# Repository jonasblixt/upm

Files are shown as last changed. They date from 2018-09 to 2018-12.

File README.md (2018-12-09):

## UPM - USB Power Monitor

This device monitors current and voltage for USB powered devices.

# Hardware
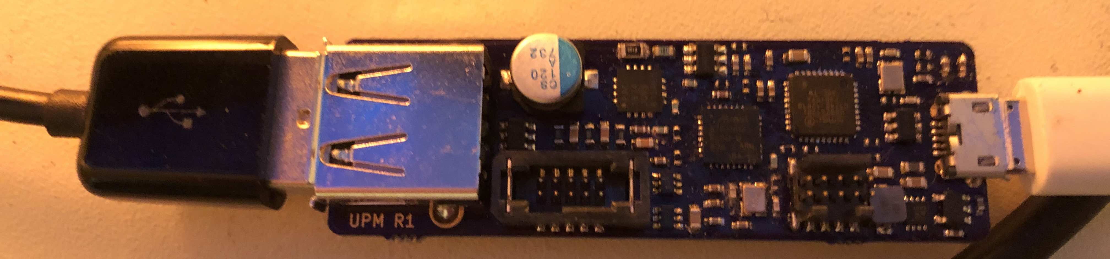
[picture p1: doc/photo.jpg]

Assembled PCB 

The PCB is a four layer board, manufactured by OSH Park. The boards can
 be ordered [here](https://oshpark.com/shared_projects/uE5lZDkP)

Schematics, layout and BOM can be found [here](https://github.com/jonpe960/upm/tree/master/hw/Release/R1)

# System description
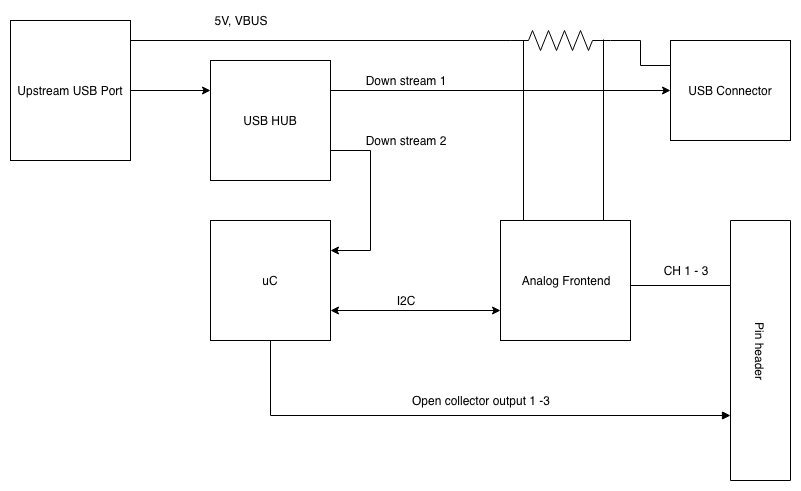
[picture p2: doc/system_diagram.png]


The device has a built in, two port, USB hub. One of the down stream ports
connects to the USB A connector and the other down stream port is connected to
the microcontroller.

An integrade analog frontend that contains a 16 bit ADC and differential
amplifier measures the voltage and current of the down stream VBUS supply. Three
auxillary diff inputs are available on a pin header.

It is possible to control the output VBUS with the on board power switch, which
also has built in short circuit protection. Three auxillary, open collector,
outputs are available on pin header.

# Ncurses TUI

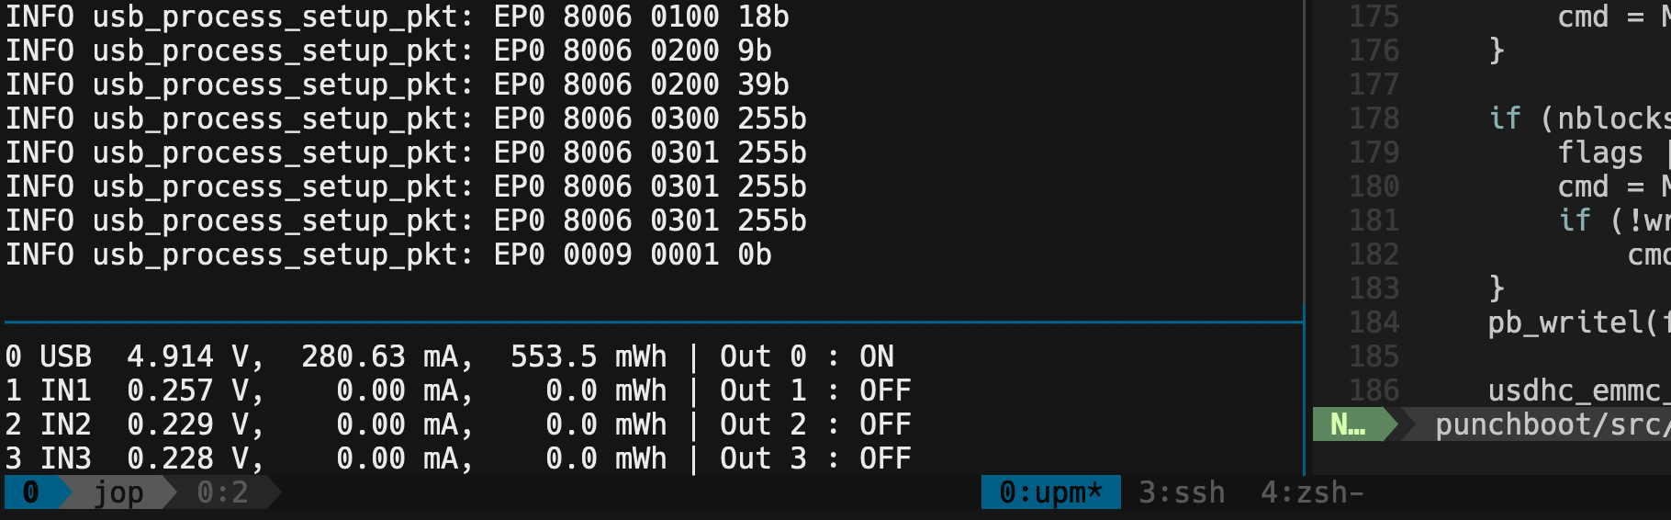
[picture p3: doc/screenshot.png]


The ncurses based TUI, displaying voltage, current and energy usage. 
Outputs can be controled from the TUI:
 - A/a VBUS on/off
 - S/s out1 on/off
 - D/d out2 on/off
 - F/f out3 on/off
 - r Reset energy counters

# Intended usage

This project came from a need to remotley monitor and power cycle USB powered devices.

# Future improvements

 - Add domain/tcp socket listener for remote control
 - Support for logging

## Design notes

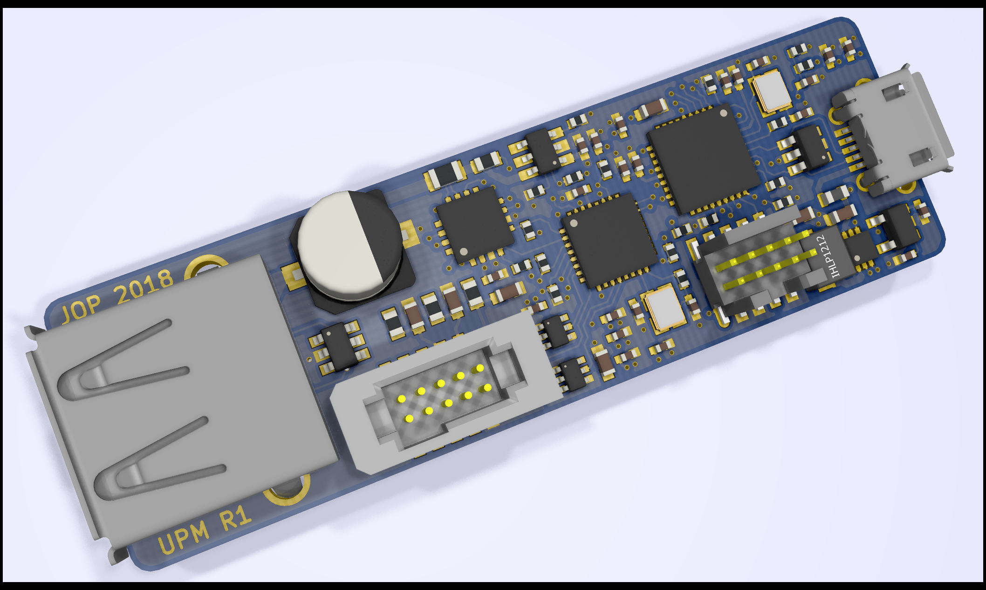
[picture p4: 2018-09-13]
hw/Release/R1/UPM R1 render.png

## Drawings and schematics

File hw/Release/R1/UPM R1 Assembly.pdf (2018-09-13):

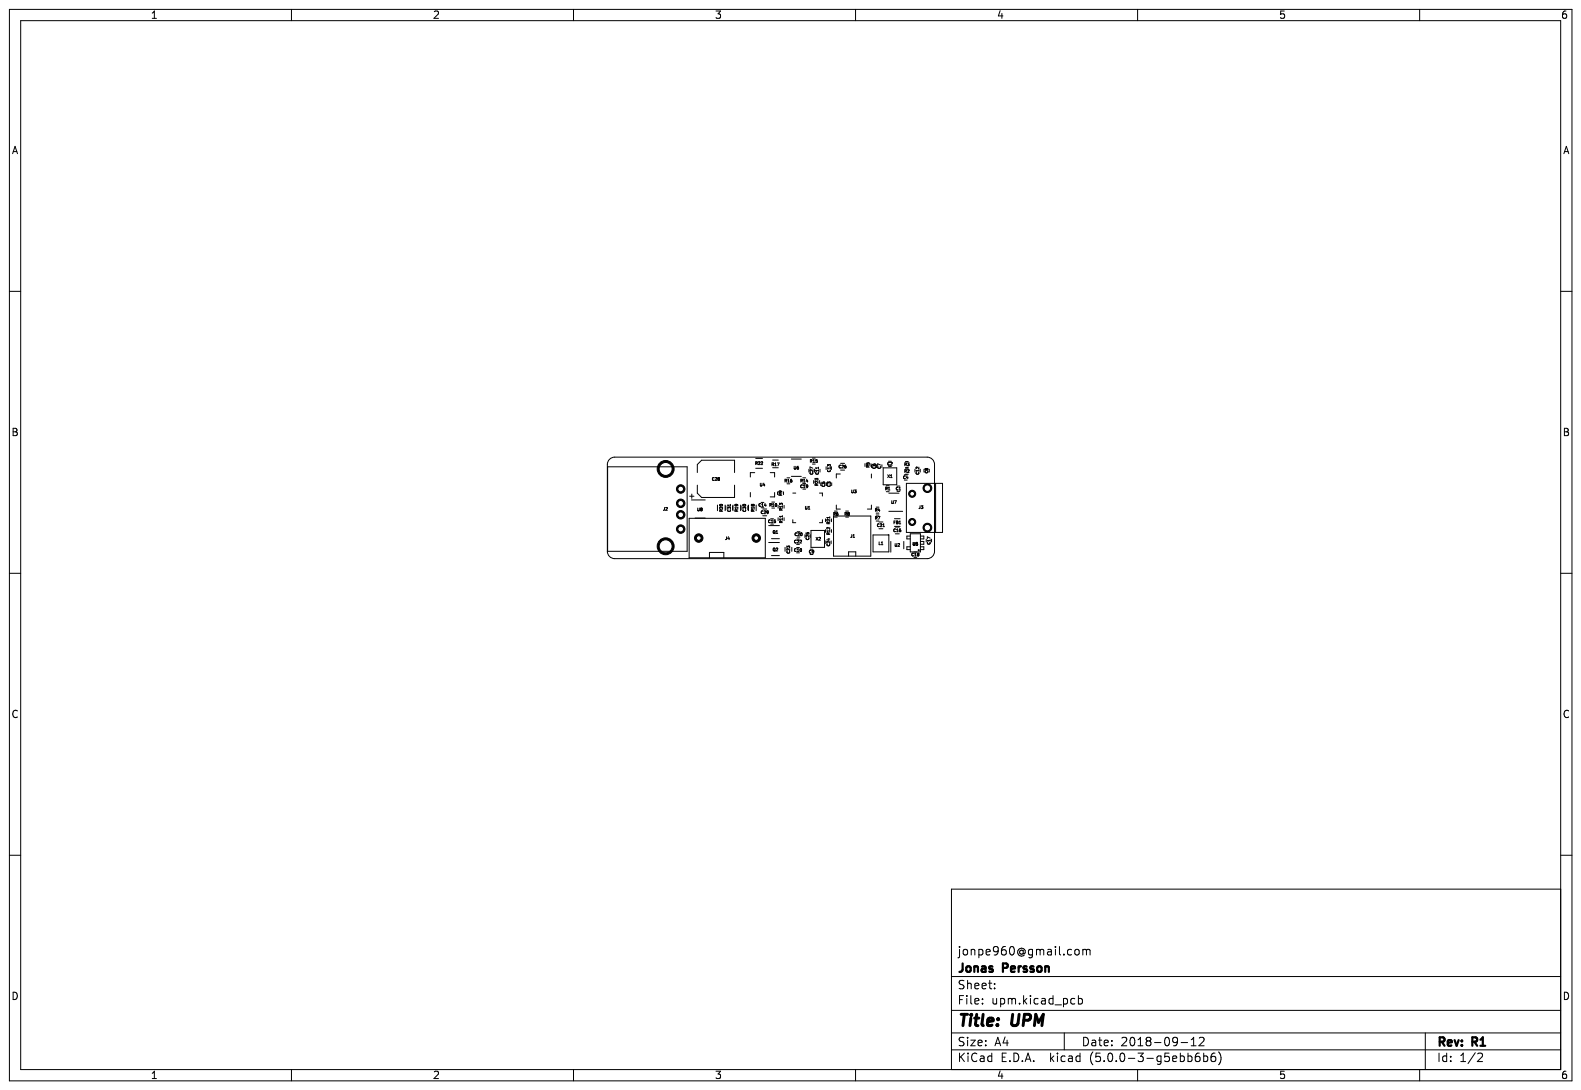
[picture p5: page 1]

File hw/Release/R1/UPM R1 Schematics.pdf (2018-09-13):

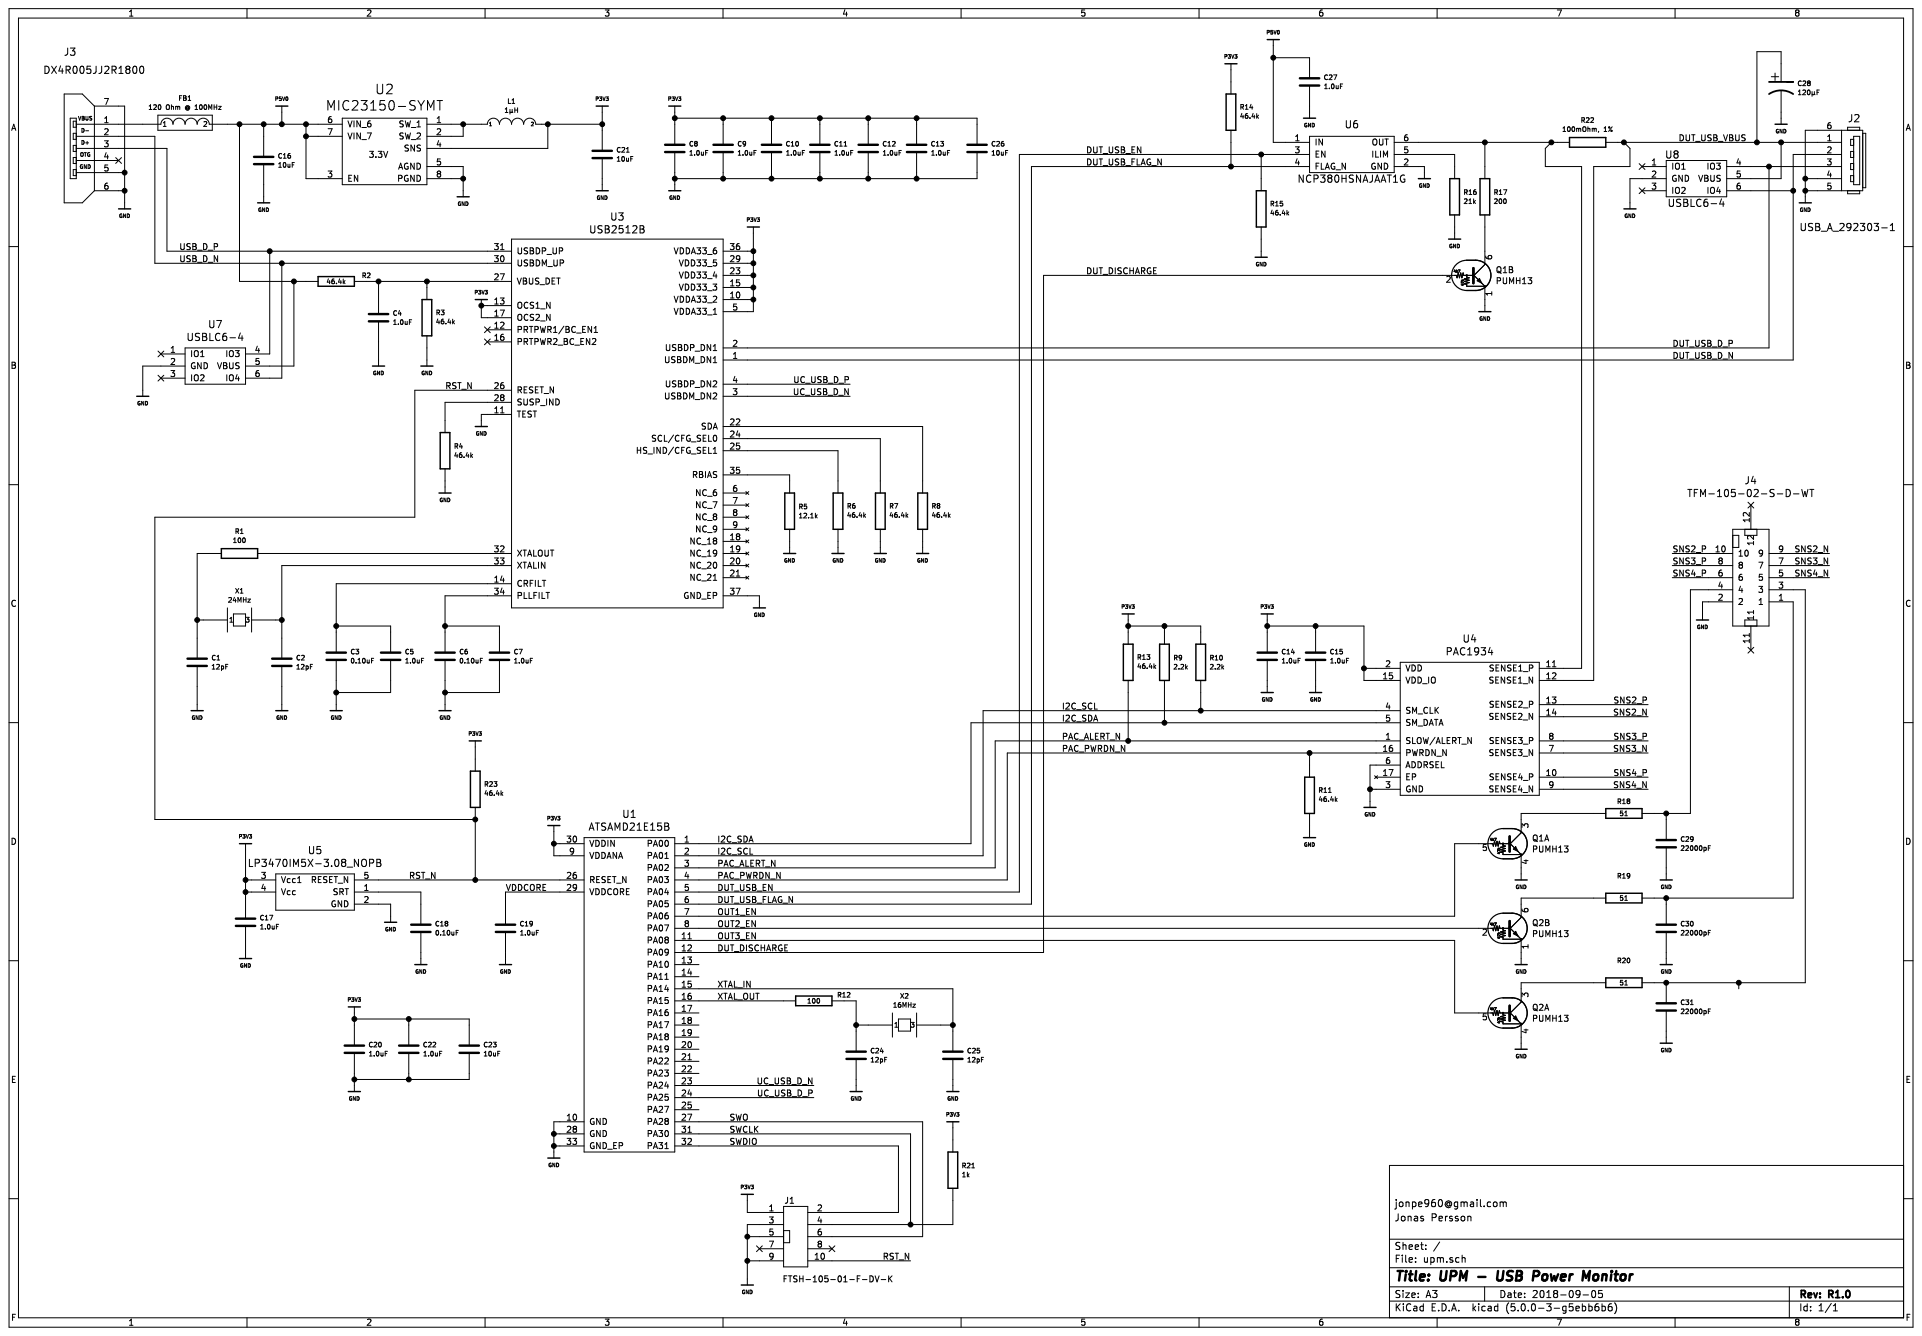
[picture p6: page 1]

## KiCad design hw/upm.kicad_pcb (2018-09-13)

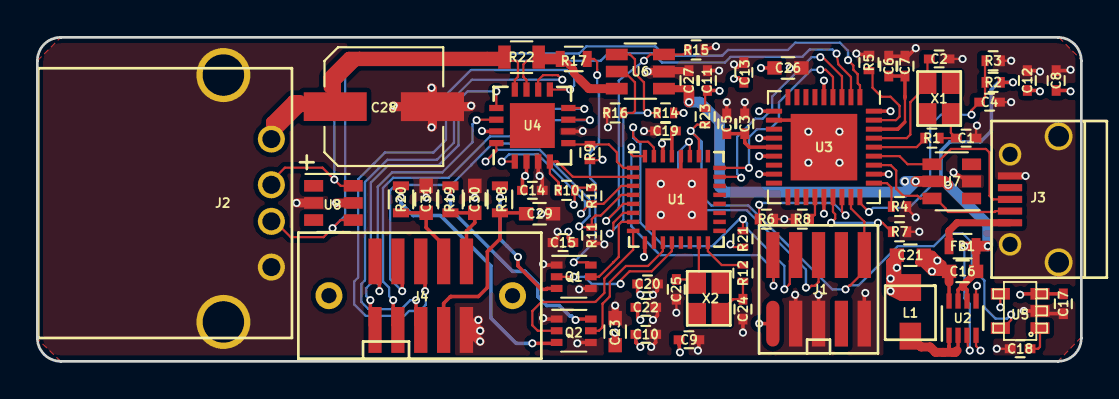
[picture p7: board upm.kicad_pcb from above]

Board: 4 copper layers, 58.0 x 18.0 mm, 72 parts (0 on the bottom side), 57 nets.

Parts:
C1, C2, C24, C25: C0402_12p_25Vdc_C0G_2; C0402
C3, C6, C18: C0402_100n_25Vdc_X7R; C0402
C4, C5, C7, C8, C9, C10, C11, C12, C13, C14, C15, C17, C19, C20, C22, C27: C0402_1u_6.3Vdc_X7R; C0402
C16, C21, C23, C26: C0603_10u_10Vdc_X7R; C0603
C28: PCAP_120u_4; CP_Elec_6.3x5.8
C29, C30, C31: C0603_22n_100Vdc_X7R; C0603
FB1: BL0603_BLM18BB121SN1D; L0603
J1: FTSH-105-01-F-DV-K
J2: USB_A_292303-1; USB_A_TH
J3: DX4R005JJ2R1800; USB_Micro-B
J4: TFM-105-02-S-D-WT
L1: IHLP1212_1u_1; IHLP1212
Q1, Q2: PUMH13; SOT-363_SC-70-6
R1, R12: R0402_100R; R0402
R2, R3, R4, R6, R7, R8, R11, R13, R14, R15, R23: R0402_46k40; R0402
R5: R0402_12k10; R0402
R9, R10: R0402_2k20; R0402
R16: R0402_21k; R0402
R17: R0603_200R; R0603
R18, R19, R20: R0603_51R; R0603
R21: R0402_1k; R0402
R22: R0805_0R1; R0805
U1: ATSAMD21E15B; QFN-32-1EP_5x5mm_Pitch0.5mm
U2: MIC23150-SYMT; DFN-8_2x2mm_Pitch0.5mm
U3: USB2512B; QFN-36-1EP_6x6mm_Pitch0.5mm
U4: PAC1934; QFN-16-1EP_4x4mm_Pitch0.65mm
U5: LP3470IM5X-3.08_NOPB; SOT-23-5
U6: NCP380HSNAJAAT1G; TSOT-23-6
U7, U8: USBLC6-4; SOT-23-6
X1: NX2520SA-24.000000MHZ; NX2520SA
X2: NX2520SA-16.000000MHZ; NX2520SA

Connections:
/DUT_DISCHARGE: Q1.2, U1.12
/DUT_USB_D_N: J2.2, U3.1, U8.6
/DUT_USB_D_P: J2.3, U3.2, U8.4
/DUT_USB_EN: R15.2, U1.5, U6.3
/DUT_USB_FLAG_N: R14.1, U1.6, U6.4
/DUT_USB_VBUS: C28.1, J2.1, R22.1, U4.12, U8.5
/I2C_SCL: R10.2, U1.2, U4.4
/I2C_SDA: R9.2, U1.1, U4.5
/OUT1_EN: Q1.5, U1.7
/OUT2_EN: Q2.2, U1.8
/OUT3_EN: Q2.5, U1.11
/PAC_ALERT_N: R13.1, U1.3, U4.1
/PAC_PWRDN_N: R11.2, U1.4, U4.16
/RST_N: J1.10, R23.1, U1.26, U3.26, U5.5
/SNS2_N: J4.9, U4.14
/SNS2_P: J4.10, U4.13
/SNS3_N: J4.7, U4.7
/SNS3_P: J4.8, U4.8
/SNS4_N: J4.5, U4.9
/SNS4_P: J4.6, U4.10
/SWCLK: J1.4, R21.2, U1.31
/SWDIO: J1.2, U1.32
/SWO: J1.6, U1.27
/UC_USB_D_N: U1.23, U3.3
/UC_USB_D_P: U1.24, U3.4
/USB_D_N: J3.2, U3.30, U7.6
/USB_D_P: J3.3, U3.31, U7.4
/VDDCORE: C19.1, U1.29
/XTAL_IN: C25.1, U1.15, X2.3
/XTAL_OUT: R12.2, U1.16
GND: C1.2, C2.2, C3.2, C4.2, C5.2, C6.2, C7.2, C8.2, C9.2, C10.2, C11.2, C12.2, C13.2, C14.2, C15.2, C16.2, C17.2, C18.2, C19.2, C20.2, C21.2, C22.2, C23.2, C24.2, C25.2, C26.2, C27.2, C28.2, C29.2, C30.2, C31.2, J1.3, J1.5, J1.9, J2.4, J2.5, J2.6, J3.5, J3.6, J3.7, J4.2, Q1.1, Q1.4, Q2.1, Q2.4, R3.1, R4.2, R5.2, R6.1, R7.1, R8.1, R11.1, R15.1, R16.2, U1.10, U1.28, U1.33, U2.5, U2.8, U3.11, U3.37, U4.3, U4.6, U5.2, U6.2, U7.2, U8.2
unnamed: C1.1, R1.2, X1.1
unnamed: C2.1, U3.33, X1.3
unnamed: C3.1, C5.1, U3.14
unnamed: C4.1, R2.1, R3.2, U3.27
unnamed: C6.1, C7.1, U3.34
unnamed: C18.1, U5.1
unnamed: C24.1, R12.1, X2.1
unnamed: C29.1, J4.4, R18.1
unnamed: C30.1, J4.1, R19.1
unnamed: C31.1, J4.3, R20.1
unnamed: FB1.1, J3.1
unnamed: L1.1, U2.1, U2.2
unnamed: Q1.3, R18.2
unnamed: Q1.6, R17.2
unnamed: Q2.3, R20.2
unnamed: Q2.6, R19.2
unnamed: R1.1, U3.32
unnamed: R4.1, U3.28
unnamed: R5.1, U3.35
unnamed: R6.2, U3.25
unnamed: R7.2, U3.24
unnamed: R8.2, U3.22
unnamed: R16.1, U6.5
unnamed: R17.1, R22.2, U4.11, U6.6
P3V3: C8.1, C9.1, C10.1, C11.1, C12.1, C13.1, C14.1, C15.1, C17.1, C20.1, C21.1, C22.1, C23.1, C26.1, J1.1, L1.2, R9.1, R10.1, R13.2, R14.2, R21.1, R23.2, U1.9, U1.30, U2.4, U3.5, U3.10, U3.13, U3.15, U3.17, U3.23, U3.29, U3.36, U4.2, U4.15, U5.3, U5.4
P5V0: C16.1, C27.1, FB1.2, R2.2, U2.3, U2.6, U2.7, U6.1, U7.5

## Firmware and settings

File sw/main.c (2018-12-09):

/**
 * UPM
 *
 * Copyright (C) 2018 Jonas Persson <jonpe960@gmail.com>
 *
 * SPDX-License-Identifier: BSD-3-Clause
 *
 */
#include <stdint.h>

#include "samd21.h"
#include "usb.h"
#include "upm.h"
#include "i2c.h"
#include "protocol.h"
#include "pac193x.h"

int main(void)
{
    uint32_t reg;

    /* Unused PIN Configuration */
    write32(PORT + PORT_DIRSET, UNUSED_PINS);
    write32(PORT + PORT_OUTCLR, UNUSED_PINS);

    /* Configure outputs */
    write32(PORT + PORT_DIRSET, PIN_DUT_USB_EN);
    write32(PORT + PORT_DIRSET, PIN_PACPWRDN_N);
    write32(PORT + PORT_DIRSET, PIN_OUT1_EN);
    write32(PORT + PORT_DIRSET, PIN_OUT2_EN);
    write32(PORT + PORT_DIRSET, PIN_OUT3_EN);
    write32(PORT + PORT_DIRSET, PIN_DUT_DISCHARGE);

    /* Configure inputs */
    write32(PORT + PORT_DIRCLR, PIN_PAC_ALERT_N);
    write32(PORT + PORT_DIRCLR, PIN_DUT_USB_FLAG_N);


    /* Set output default values */
    write32(PORT + PORT_OUTSET, PIN_DUT_USB_EN);
    write32(PORT + PORT_OUTSET, PIN_PACPWRDN_N);
    write32(PORT + PORT_OUTCLR, PIN_OUT1_EN);
    write32(PORT + PORT_OUTCLR, PIN_OUT2_EN);
    write32(PORT + PORT_OUTCLR, PIN_OUT3_EN);
    write32(PORT + PORT_OUTCLR, PIN_DUT_DISCHARGE);

    /* PAD Mux */
    
    /* PA1 = Sercom1/pad1, PA0 = Sercom1/pad0 */

    write32(PORT + PORT_WRCONFIG, (1 << 30) | (1 << 28) | 
                                  (MUX_D << 24) |
                                  (1 << 16) |
                                  (1 << 0) |
                                  (1 << 1));

    /* PA25 = USB_DP, PA24 = USB_DM */

    write32(PORT + PORT_WRCONFIG, (1 << 31) | (1 << 30) | (1 << 28) | 
                                  (MUX_G << 24) |
                                  (1 << 16) |
                                  (1 << 8) |
                                  (1 << 9));


    /* Enable SERCOM 1 clock */
    reg = read32(PM + PM_APBCMASK);
    reg |= (1 << 3);
    write32(PM + PM_APBCMASK, reg);
    
    write16(GCLK + GCLK_CLKCTRL, (1 << 14) | GCLK_ID_SERCOMx_SLOW);
    write16(GCLK + GCLK_CLKCTRL, (1 << 14) | GCLK_ID_SERCOM1_CORE);

    //write32(NVIC_ISER, (1 << SERCOM1_IRQn));

    i2c_init(SERCOM1);


    /* Enable and connect USB clock to generator 0 */
    write16(GCLK + GCLK_CLKCTRL, (1 << 14) | GCLK_ID_USB);

    pac193x_init(0x20);

    usb_init(USB);
    struct upm_in in;

    while(1) 
    {
        usb_task();

        if (usb_enumerated()) 
        {
            
            pac193x_refresh();

            for (uint32_t i = 0; i < 0xfff; i++)
                asm("nop");

            for (uint32_t i = 0; i < 4; i++)
            {
                in.Vbus[i] = pac193x_vbus(i);
                in.Vsns[i] = pac193x_vsns(i);
                pac193x_pwr(i, in.Ereg[i]);
            }

            usb_send((uint8_t *) &in, sizeof(struct upm_in));

            if (usb_has_data())
            {
                struct upm_out *out = (struct upm_out *) usb_get_buf();

                if (out->outputs_set & (1 << 0))
                {
                    in.outputs |= (1 << 0);
                    write32(PORT + PORT_OUTCLR, PIN_DUT_DISCHARGE);
                    write32(PORT + PORT_OUTSET, PIN_DUT_USB_EN);
                }

                if (out->outputs_clr & (1 << 0))
                {
                    in.outputs &= ~(1 << 0); 
                    write32(PORT + PORT_OUTSET, PIN_DUT_DISCHARGE);
                    write32(PORT + PORT_OUTCLR, PIN_DUT_USB_EN);
                }


                if (out->outputs_set & (1 << 1))
                {
                    in.outputs |= (1 << 1);
                    write32(PORT + PORT_OUTSET, PIN_OUT1_EN);
                }


                if (out->outputs_clr & (1 << 1))
                {
                    in.outputs &= ~(1 << 1);
                    write32(PORT + PORT_OUTCLR, PIN_OUT1_EN);
                }


                if (out->outputs_set & (1 << 2))
                {
                    in.outputs |= (1 << 2);
                    write32(PORT + PORT_OUTSET, PIN_OUT2_EN);
                }


                if (out->outputs_clr & (1 << 2))
                {
                    in.outputs &= ~(1 << 2);
                    write32(PORT + PORT_OUTCLR, PIN_OUT2_EN);
                }


                if (out->outputs_set & (1 << 3))
                {
                    in.outputs |= (1 << 3);
                    write32(PORT + PORT_OUTSET, PIN_OUT3_EN);
                }


                if (out->outputs_clr & (1 << 3))
                {
                    in.outputs &= ~(1 << 3);
                    write32(PORT + PORT_OUTCLR, PIN_OUT3_EN);
                }

                if (out->counter_reset & (1 << 0))
                {
                    pac193x_reset_counters();
                }

            }

        }
    }
}

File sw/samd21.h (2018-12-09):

/**
 * UPM
 *
 * Copyright (C) 2018 Jonas Persson <jonpe960@gmail.com>
 *
 * SPDX-License-Identifier: BSD-3-Clause
 *
 */
#ifndef __SAMD21_H__
#define __SAMD21_H__

#include <stdint.h>

static inline void write32(uint32_t reg, uint32_t val)
{
    *((volatile uint32_t *) reg) = val;
}

static inline uint32_t read32(uint32_t reg)
{
    return *((volatile uint32_t *)reg);
}


static inline void write16(uint32_t reg, uint16_t val)
{
    *((volatile uint16_t *) reg) = val;
}

static inline uint16_t read16(uint32_t reg)
{
    return *((volatile uint16_t *)reg);
}


static inline void write8(uint32_t reg, uint8_t val)
{
    *((volatile uint8_t *) reg) = val;
}

static inline uint8_t read8(uint32_t reg)
{
    return *((volatile uint8_t *)reg);
}

/* Cortex M0+ Registers */

#define SCS_BASE                       (0xE000E000)
#define SysTick_BASE        (SCS_BASE +  0x0010UL)                    /*!< SysTick Base Address */
#define NVIC_BASE           (SCS_BASE +  0x0100UL)                    /*!< NVIC Base Address */
#define SCB_BASE            (SCS_BASE +  0x0D00UL)                    /*!< System Control Block Base Address */

#define NVIC_ISER           (NVIC_BASE + 0x000)
#define NVIC_ICER           (NVIC_BASE + 0x080)
#define NVIC_ISPR           (NVIC_BASE + 0x100)
#define NVIC_ICPR           (NVIC_BASE + 0x180)
#define NVIC_IP             (NVIC_BASE + 0x300)

/* SAMD21 Registers */

#define AC                            (0x42004400) /**< \brief (AC) APB Base Address */
#define ADC                           (0x42004000) /**< \brief (ADC) APB Base Address */
#define DAC                           (0x42004800) /**< \brief (DAC) APB Base Address */
#define DMAC                          (0x41004800) /**< \brief (DMAC) APB Base Address */
#define DSU                           (0x41002000) /**< \brief (DSU) APB Base Address */
#define EIC                           (0x40001800) /**< \brief (EIC) APB Base Address */
#define EVSYS                         (0x42000400) /**< \brief (EVSYS) APB Base Address */
#define GCLK                          (0x40000C00) /**< \brief (GCLK) APB Base Address */
#define SBMATRIX                      (0x41007000) /**< \brief (SBMATRIX) APB Base Address */
#define I2S                           (0x42005000) /**< \brief (I2S) APB Base Address */
#define MTB                           (0x41006000) /**< \brief (MTB) APB Base Address */
#define NVMCTRL_AUX3                  (0x0080A000) /**< \brief (NVMCTRL) AUX3 Base Address */
#define NVMCTRL                       (0x41004000) /**< \brief (NVMCTRL) APB Base Address */
#define NVMCTRL_CAL                   (0x00800000) /**< \brief (NVMCTRL) CAL Base Address */
#define NVMCTRL_LOCKBIT               (0x00802000) /**< \brief (NVMCTRL) LOCKBIT Base Address */
#define NVMCTRL_OTP1                  (0x00806000) /**< \brief (NVMCTRL) OTP1 Base Address */
#define NVMCTRL_OTP2                  (0x00806008) /**< \brief (NVMCTRL) OTP2 Base Address */
#define NVMCTRL_OTP4                  (0x00806020) /**< \brief (NVMCTRL) OTP4 Base Address */
#define NVMCTRL_TEMP_LOG              (0x00806030) /**< \brief (NVMCTRL) TEMP_LOG Base Address */
#define NVMCTRL_USER                  (0x00804000) /**< \brief (NVMCTRL) USER Base Address */
#define PAC0                          (0x40000000) /**< \brief (PAC0) APB Base Address */
#define PAC1                          (0x41000000) /**< \brief (PAC1) APB Base Address */
#define PAC2                          (0x42000000) /**< \brief (PAC2) APB Base Address */
#define PM                            (0x40000400) /**< \brief (PM) APB Base Address */
#define PORT                          (0x41004400) /**< \brief (PORT) APB Base Address */
#define PORT_IOBUS                    (0x60000000) /**< \brief (PORT) IOBUS Base Address */
#define PTC                           (0x42004C00) /**< \brief (PTC) APB Base Address */
#define RTC                           (0x40001400) /**< \brief (RTC) APB Base Address */
#define SERCOM0                       (0x42000800) /**< \brief (SERCOM0) APB Base Address */
#define SERCOM1                       (0x42000C00) /**< \brief (SERCOM1) APB Base Address */
#define SERCOM2                       (0x42001000) /**< \brief (SERCOM2) APB Base Address */
#define SERCOM3                       (0x42001400) /**< \brief (SERCOM3) APB Base Address */
#define SYSCTRL                       (0x40000800) /**< \brief (SYSCTRL) APB Base Address */
#define TC3                           (0x42002C00) /**< \brief (TC3) APB Base Address */
#define TC4                           (0x42003000) /**< \brief (TC4) APB Base Address */
#define TC5                           (0x42003400) /**< \brief (TC5) APB Base Address */
#define TCC0                          (0x42002000) /**< \brief (TCC0) APB Base Address */
#define TCC1                          (0x42002400) /**< \brief (TCC1) APB Base Address */
#define TCC2                          (0x42002800) /**< \brief (TCC2) APB Base Address */
#define USB                           (0x41005000) /**< \brief (USB) APB Base Address */
#define WDT                           (0x40001000) /**< \brief (WDT) APB Base Address */

/* GCLK */

#define GCLK_CTRL            0x00
#define GCLK_STATUS          0x01
#define GCLK_CLKCTRL         0x02
#define GCLK_GENCTRL         0x04
#define GCLK_GENDIV          0x08

#define GCLK_ID_SERCOMx_SLOW 0x13
#define GCLK_ID_SERCOM1_CORE 0x15
#define GCLK_ID_USB          0x06

/* SYSCTRL */

#define SYSCTRL_XOSC         0x10
#define SYSCTRL_PCLKSR       0x0C
#define SYSCTRL_DPLLCTRLA    0x44
#define SYSCTRL_DPLLCTRLB    0x4C
#define SYSCTRL_DPLLRATIO    0x48
#define SYSCTRL_DPLLSTATUS   0x50
#define SYSCTRL_INTFLAG      0x08

/* NVMCTRL */

#define NVMCTRL_CTRLB        0x04

/* PORT */

#define PORT_DIRSET          0x08
#define PORT_DIRCLR          0x04
#define PORT_OUTSET          0x18
#define PORT_OUTCLR          0x14
#define PORT_WRCONFIG        0x28

#define PORT_PMUX0           0x30
#define PORT_PMUX1           0x31
#define PORT_PMUX2           0x32
#define PORT_PMUX3           0x33
#define PORT_PMUX4           0x34
#define PORT_PMUX5           0x35
#define PORT_PMUX6           0x36
#define PORT_PMUX7           0x37
#define PORT_PMUX8           0x38
#define PORT_PMUX9           0x39
#define PORT_PMUX10          0x3A
#define PORT_PMUX11          0x3B
#define PORT_PMUX12          0x3C
#define PORT_PMUX13          0x3D
#define PORT_PMUX14          0x3E
#define PORT_PMUX15          0x3F

#define MUX_A                0x00
#define MUX_B                0x01
#define MUX_C                0x02
#define MUX_D                0x03
#define MUX_E                0x04
#define MUX_F                0x05
#define MUX_G                0x06
#define MUX_H                0x07
#define MUX_I                0x08
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

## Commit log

2018-09-04 Initial structure
    [upm.kicad_pcb, upm.sch]
2018-09-04 Added some datasheets
    [upm.kicad_pcb, upm.sch]
2018-09-13 R1 release of HW
    [upm.kicad_pcb, upm.sch]
2018-09-14 Added BOM
2019-01-15 Added timeout, under some circumstances the USB link can break down. Unless there is a timeout the device will be stuck for ever.
